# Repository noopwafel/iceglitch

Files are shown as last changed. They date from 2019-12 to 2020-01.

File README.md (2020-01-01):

# iceGLITCH

iceGLITCH is a cheap, fun and terrible voltage glitcher!

You can use it to inject faults in the voltage line of targets, making them do weird things.

You can control both the normal and glitch voltage levels, and if you squint and sort of wave your hands a lot, then you can pretend you get ~200ps of resolution for the glitch length (time that the voltage is changed from normal to glitch level). Accuracy, on the other hand, is left as an exercise for the reader..

Many people played with this at the 'Hardware Slackers' assembly at 36C3! We're still recovering and will update the repository once we've gotten a few days of good sleep.

This is what a typical setup looks like:

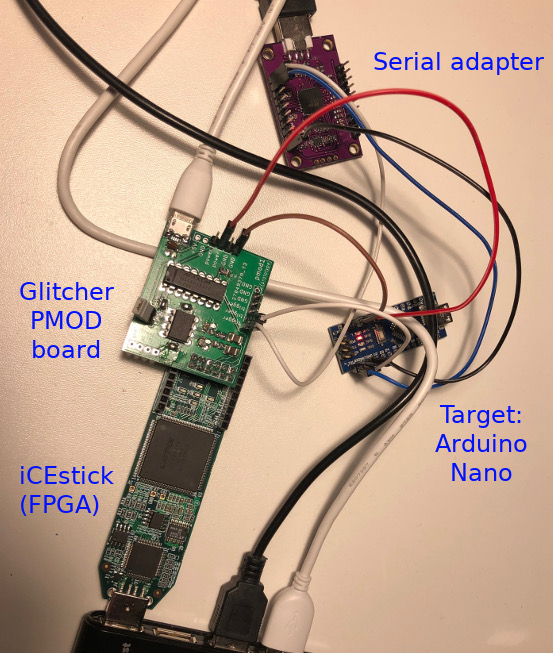
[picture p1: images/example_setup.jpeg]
Image of iceGLITCH setup


And this is an example of what a real-world attack looks like (from our 36C3 assembly):

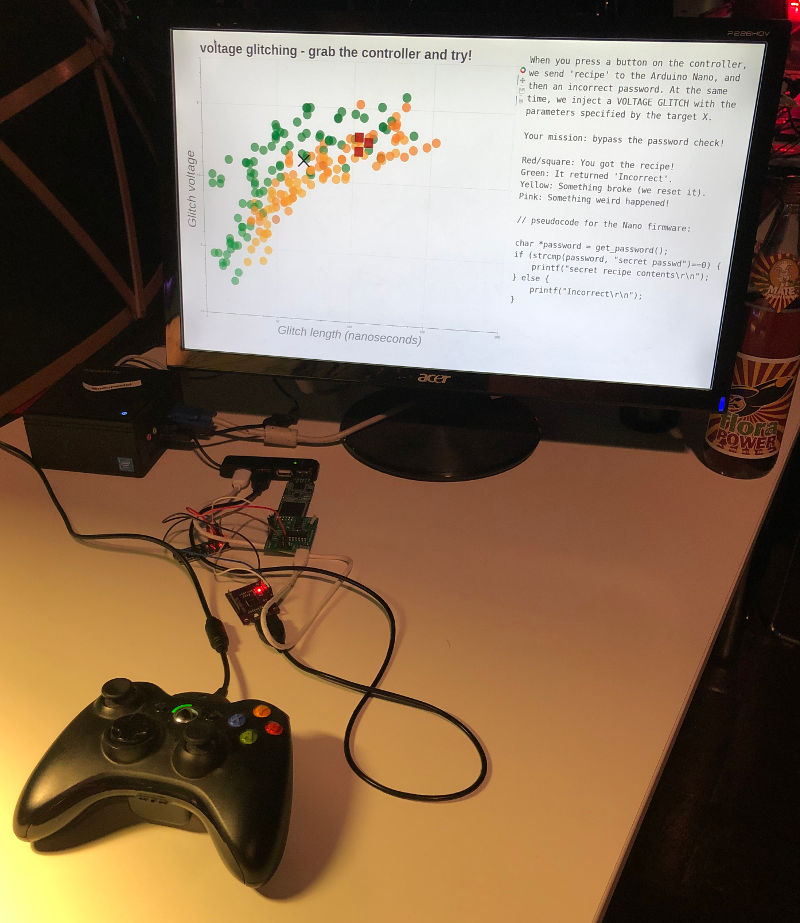
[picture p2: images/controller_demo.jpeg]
Game controller glitch setup


# Hardware

You can solder a good-enough (fun!) version of this glitcher using protoboard,
but nowadays we use a PCB version (see the 'pcb' directory). You can solder several
different combinations of components to get different glitcher designs, some of which make more
sense than others; however, we guarantee that all combinations will be both terrible and fun.

You can use it with any ICE40HX FPGA board with a PMOD connector; we're using the cheap (~22eur) 'iCEstick'.

Also it turns out you don't have to solder it nicely, it'll work fine anyway:

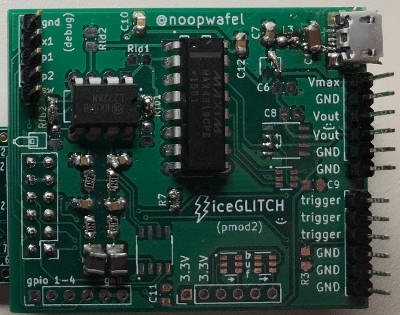
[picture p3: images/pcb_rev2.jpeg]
Image of badly-soldered rev2 board


# Code

The 'TOE' directory contains code for some example targets.

The FPGA code (to be built using the open source yosys/nextpnr toolchain) is in the 'fpga' directory. We can't write verilog, there are no test cases, it is all terrible. We are sorry, our code is bad and we should feel bad. But it works :D

The (python) scripts are in the 'scripts' directory, including scripts to attack the example targets.

## History/Context

We built a horrible, horrible 5eur "oscilloscope" for our 35C3 side channel analysis workshop:
the [HorrorScope](https://github.com/albert-spruyt/HorrorScope).
This glitcher is our attempt to build a similar cheap-and-cheerful workshop platform for voltage glitching.

Some of our friends used it at the HITB CyberWeek in [October 2019](https://twitter.com/AllOurFaults/status/1184734015699464192), and we "released" it at 36C3 in December 2019.

Thanks to everyone who helped inspire or test our hacks, and thanks to @nedos in particular for making us realize we could
just use a cheap analog switch rather than overcomplicating things!

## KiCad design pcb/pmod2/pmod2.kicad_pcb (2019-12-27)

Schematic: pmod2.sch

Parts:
C1, C2, C3, C4, C5, C6, C7, C8, C9, C10, C11, C12, C13: C; C_0805_2012Metric_Pad1.15x1.40mm_HandSolder
J1: USB_B_Micro; USB_Micro-B_Amphenol_hax
J2: PMOD; PinHeader_2x06_P2.54mm_Vertical
J3, J4, J6, J7: Conn_01x04; PinHeader_1x06_P2.54mm_Vertical
J5: Conn_01x04; PinHeader_1x05_P2.54mm_Vertical
L1, L2: L; L_1210_3225Metric_Pad1.42x2.65mm_HandSolder
L3: Ferrite_Bead_Small; L_0805_2012Metric_Pad1.15x1.40mm_HandSolder
R1, R2, R3, R4, R5, R7: R; R_0805_2012Metric_Pad1.15x1.40mm_HandSolder
Rfb1, Rfb2, Rfb3, Rfb4: 0; R_0805_2012Metric_Pad1.15x1.40mm_HandSolder
Rld1, Rld2: R; R_0805_2012Metric_Pad1.15x1.40mm_HandSolder
U1: L272M; DIP-8_W7.62mm_LongPads
U2: MAX4619; DIP-16_W7.62mm_LongPads
U3: MCP4822; SOIC-8_3.9x4.9mm_P1.27mm
U4: TS5A63157; SOT-23-6
U5, U6: trigger; SOT-23-6
U7: MAX4232; SOT-23-8
U8: AP2210N-4.0; TSOT-23
U9: THS4631DDA; SOIC-8_3.9x4.9mm_P1.27mm

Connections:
+3V3: J2.6, J2.12, J7.1, J7.2, U5.5, U6.5
+5V: C6.2, C8.2, C9.2, C10.2, C11.2, C12.2, C13.2, J3.6, U1.2, U2.16, U3.1 (Vdd), U4.5, U7.8, U8.2, U9.7
/AMPFB1: Rfb1.2, Rfb3.1, U1.8, U7.2
/AMPFB2: Rfb2.2, Rfb4.2, U1.5, U7.6
/AMPOUT1: Rfb1.1, Rld1.1, U1.1, U2.2, U2.5, U2.12, U4.3, U7.1
/AMPOUT2: Rfb2.1, Rld2.2, U1.3, U2.1, U2.3, U2.13, U4.1, U7.7
/BUF1_IN: J7.3, U5.2
/BUF1_OUT: J7.4, U5.4
/BUF2_IN: J7.5, U6.2
/BUF2_OUT: J7.6, U6.4
/GPIO1: J2.3, J6.1
/GPIO2: J2.4, J6.2
/GPIO3: J2.7, J6.3
/POWER_OUT: J3.3, J3.4, U9.2, U9.6
/POWER_PREOUT: U2.4, U2.14, U2.15, U4.4, U9.3
/PWM_FILT1: C3.1, R4.1, U1.7, U3.6 (VB), U7.3
/PWM_FILT2: C5.1, R5.1, U1.6, U3.8 (VA), U7.5
/PWM_IN1: J2.9, J5.3, L1.2, U3.3 (SCK)
/PWM_IN2: J2.10, J5.2, L2.2, U3.2 (~CS)
/SDI_IN: J2.8, J5.4, J6.4, U3.4 (SDI)
/SWITCH_IN: J2.2, J5.1, R7.2, U2.9, U2.10, U2.11, U4.6
/TRIGGER_OUT: J2.1, J4.1, J4.2, J4.3, R3.2
GND: C1.1, C2.2, C3.2, C4.2, C5.2, C6.1, C7.1, C8.1, C9.1, C10.1, C11.1, C12.1, C13.1, J1.5, J2.5, J2.11, J3.1, J3.2, J3.5, J4.4, J4.5, J4.6, J5.5, J6.5, J6.6, R3.1, R7.1, Rfb3.2, Rfb4.1, Rld1.2, Rld2.1, U1.4, U2.6, U2.8, U3.5 (~LDAC), U3.7 (Vss), U4.2, U5.3, U6.3, U7.4, U8.1, U9.4
unnamed: C1.2, J1.1, L3.2
unnamed: C2.1, R1.1, R4.2
unnamed: C4.1, R2.1, R5.2
unnamed: C7.2, L3.1, U8.3
unnamed: L1.1, R1.2
unnamed: L2.1, R2.2

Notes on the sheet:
PWM filter/caps
pre-switch opamp
debug/extras
interface

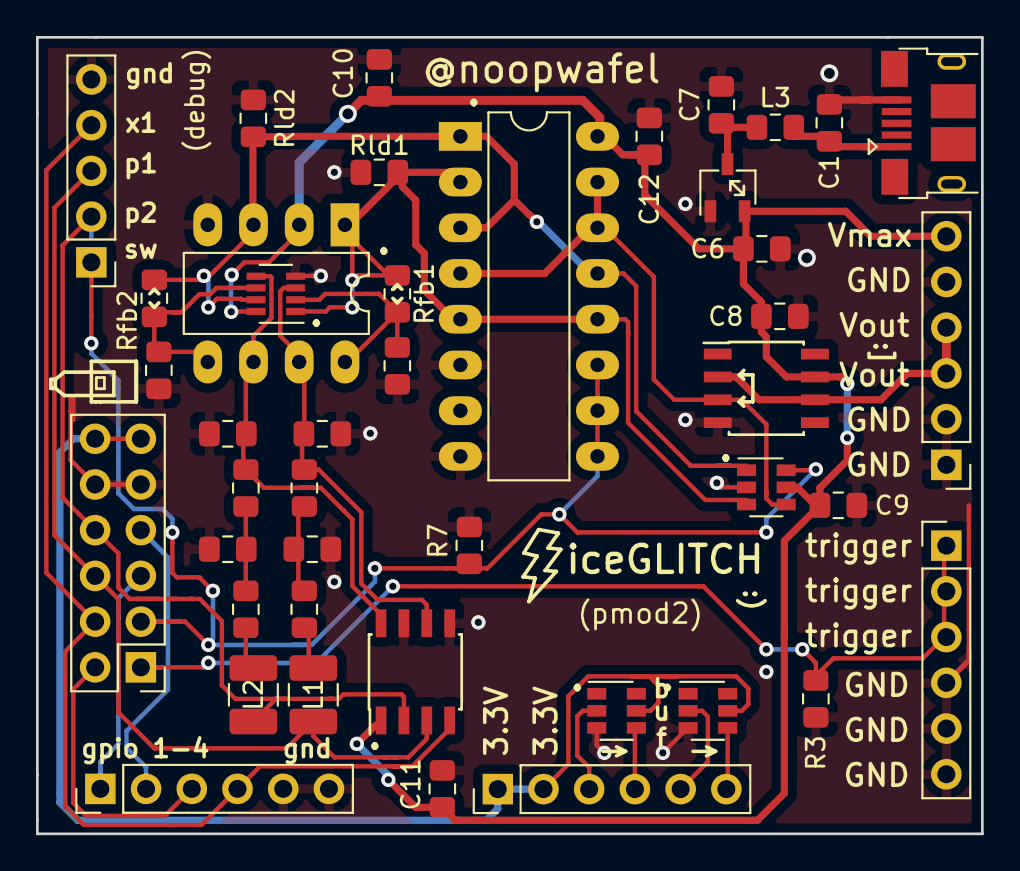
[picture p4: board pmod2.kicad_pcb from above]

Board: 2 copper layers, 52.5 x 44.2 mm, 44 parts (1 on the bottom side), 29 nets.

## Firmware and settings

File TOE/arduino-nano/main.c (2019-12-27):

#define F_CPU 16000000UL
#define USART_BAUDRATE 19200
#define BAUD_PRESCALE  ((F_CPU /  (USART_BAUDRATE * 16UL)) -1 )

#include <avr/io.h>
#include <avr/interrupt.h>
#include <string.h>


static void usart_init(){
    UBRR0L = BAUD_PRESCALE & 0xff;
    UBRR0H = BAUD_PRESCALE >> 8;
    UCSR0B = (1<<TXEN0) | (1<<RXEN0);
}

static uint8_t usart_getchar(){
    while( (UCSR0A & (1<<RXC0)) == 0);
        return UDR0;
}

static void usart_gets(char* buf,int maxLen){
	for(int i=0;i<maxLen;i++){
		buf[i] = usart_getchar();
		if(buf[i] == 0 || buf[i] == '\r' || buf[i] == '\n'){
			buf[i] = 0;
			break;
		}
	}
	buf[maxLen-1] = 0;
}

static void usart_putchar(uint8_t val){
    while( (UCSR0A & (1<<UDRE0)) == 0);
        UDR0 = val;
}

static void usart_putshort(uint16_t val){
    usart_putchar(val >> 8);
    usart_putchar(val & 0xff);
}

static void usart_putstring(char* string){
    for(;*string;string++)
        usart_putchar((uint8_t)*string);
}
static void usart_getbuf(uint8_t* buf,uint8_t len){
    for(uint8_t i=0;i<len;i++)
        buf[i] = usart_getchar();
}


static const uint8_t pin[] = {'9','1','1','0'};
int main(void){
    usart_init();
    usart_putstring("Welcome to the Arduino, nano!\r\n");

    char command_buf[10] = {1};
    while(1){
	usart_gets(command_buf,sizeof(command_buf));
	if( 0 == strcmp(command_buf,"Glitching is fun!") ){
		usart_putstring("You never know whats going to fall out next!\r\n");
	}else if( 0 == strcmp(command_buf,"Look at all the weird things coming out!") ){
		usart_putstring("Maybe this is a memory dump!\r\n");
	}else if( 0 == strcmp(command_buf,"recipe")){
		usart_putstring("If you want the recipe, give the password, nano\r\n\r\n");
		usart_gets(command_buf,sizeof(command_buf));
		{
			volatile int i=0;
			volatile int j=10;
			for(;i<j;i++){
				j--;
			}
		}
		if( 0 == strcmp(command_buf,"oepsiedoepsiereallylooongoepstoolong")){
		{
			volatile int i=0;
			volatile int j=10;
			for(;i<j;i++){
				j--;
			}
		}
			usart_putstring("If you were doing the workshop, the rice would be here!\r\n");
		}else{
			usart_putstring("Incorrect\r\n");
		}
	}else if( 0 == strcmp(command_buf,"home") ){
		usart_putstring("It's beautiful, nano!\r\n");
	}else if( 0 == strcmp(command_buf,"Getting closer!") ){
		usart_putstring("almost there!\r\n");
	}else if( 0 == strcmp(command_buf,"We are slackers") ){
		usart_putstring("Wow theres a lot random stuff in here\r\n");
	}else{
		usart_putstring("Oh i don't know about that\r\n\r\n");
		usart_putstring("What would you like to know about, nano?:\r\n\r\n");
		usart_putstring("home  --- talk about home\r\n");
		usart_putstring("recipe  --- Secret recipe\r\n");
        }
    }
}

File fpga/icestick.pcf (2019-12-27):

# Generic iCEstick placement constraints file

# Red LEDs
set_io LED1 99
set_io LED2 98
set_io LED3 97
set_io LED4 96

# Green LED
set_io LED5 95

# IrDA port
#set_io RXD 106
#set_io TXD 105
#set_io SD 107

# Pmod connector
#set_io PIO1_02 78 # Pin 1
#set_io PIO1_03 79 # Pin 2
#set_io PIO1_04 80 # Pin 3
#set_io PIO1_05 81 # Pin 4
#set_io PIO1_06 87 # Pin 7
#set_io PIO1_07 88 # Pin 8
#set_io PIO1_08 90 # Pin 9
#set_io PIO1_09 91 # Pin 10

# Connector J1
#set_io PIO0_02 112 # Pin 3
#set_io PIO0_03 113 # Pin 4
#set_io PIO0_04 114 # Pin 5
#set_io PIO0_05 115 # Pin 6
#set_io PIO0_06 116 # Pin 7
#set_io PIO0_07 117 # Pin 8
#set_io PIO0_08 118 # Pin 9
#set_io PIO0_09 119 # Pin 10

# Connector J3
#set_io PIO2_17 62 # Pin 3
#set_io PIO2_16 61 # Pin 4
#set_io PIO2_15 60 # Pin 5
#set_io PIO2_14 56 # Pin 6
#set_io PIO2_13 48 # Pin 7
#set_io PIO2_12 47 # Pin 8
#set_io PIO2_11 45 # Pin 9
#set_io PIO2_10 44 # Pin 10

# FTDI Port B UART
#set_io DCDn 1
#set_io DSRn 2
#set_io DTRn 3
#set_io CTSn 4
#set_io RTSn 7
#set_io RS232_Tx_TTL 8
#set_io RS232_Rx_TTL 9
set_io TX 8
set_io RX 9

# SPI
#set_io SPI_SCK 70
#set_io SPI_SI 68
#set_io SPI_SO 67
#set_io SPI_SS_B 71

# Configuration pins
#set_io CDONE 65
#set_io CRESET_B 66

# 12 MHz clock
#set_io iCE_CLK 21
set_io clk 21

set_io trigger_in  78 # PMOD 1 & 2
set_io switch_out  79

set_io gpio_0 87
set_io gpio_1 88

#set_io clka 80
#set_io clkb 81

# https://stackoverflow.com/questions/42421906/correspondence-between-ice40-i-o-blocks-and-package-pins

set_io PWM1 90  # PMOD ...
set_io PWM2 91  # PMOD ...

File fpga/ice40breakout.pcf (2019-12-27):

set_io clk J3

set_io LED1 B5
set_io LED2 B4
set_io LED3 A2
set_io LED4 A1
set_io LED5 C5

set_io RSTn C16 -pullup yes

set_io RX B10
set_io TX B12

set_io trigger_in H16
set_io switch_out D16


set_io PWM1 B15
set_io PWM2 D15

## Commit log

2019-12-27 add pmod2 pcb
    [pmod2-B.Cu.gbr, pmod2-B.Mask.gbr, pmod2-B.Paste.gbr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]
2019-12-27 add arduino-nano TOE source
2019-12-27 add PCB image
